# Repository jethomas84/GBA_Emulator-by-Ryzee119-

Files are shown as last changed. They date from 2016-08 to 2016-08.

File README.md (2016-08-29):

# GBA_Emulator-by-Ryzee119-

This was designed by /u/Ryzee
Originally posted on Reddit here:
https://www.reddit.com/r/DIY/comments/4zbqwr/this_is_my_attempt_at_making_a_portable_emulator/

Build Photos:
http://imgur.com/a/kjFmS

I am releasing these design files in good faith that people will use them to learn something about electronics and maybe bring an old Gameboy Advance (GBA) back to life.

I don’t want to see people taking this design and knocking it off for a quick buck.
If you don’t want to deal with all this work another redditor /u/Flav0r has designed something quite similar to this. http://gamepieadvance.com/ I understand he may be working on DIY Kits.

##DISCLAIMER:
This project is NOT for the fresh beginner or the faint of heart. It requires moderate/high level soldering skills. There are many small and fine pitch components that need to be soldered. I recommend you don’t attempt this unless you have experience in soldering, a basic ability to troubleshoot electronic circuits if things aren’t working and an ability to make mods on the fly to suit your needs. i.e cutting plastic where required.
This also requires taking apart an original GBA to repurpose the case, buttons and de-soldering of several components on the GBA motherboard. This can very tricky without the right equipment.
As a minimum the following tools are recommended (All parts should be of good quality from reputable suppliers!):

1.	A decent temperature controlled soldering station with suitable tips for fine work
2.	Solder flux
3.	Leaded solder
4.	Fine tweezers (anti-magnetic)
5.	Solder wick
6.	Multimeter for testing

This is a **FIRST PROTOTYPE** board which just happened to work reasonably ok. This has not undergone any extensive testing.

I take no responsibility for the following:

1.	You went ahead and purchased everything, soldered it up and it didn’t work.
2.	You soldered an SMD chip and bent and broke the pins.
3.	If a component in the BOM is not available or becomes obsolete, use your best judgement to find a replacement.
4.	A component was missing from the BOM. (I did check it. But it’s your responsibility to check it again against the schematic)
5.	The thing burst into flame and explodes in your hands and burns your house down.
6.	It doesn’t fit in your GBA case. (It was designed to one I had lying around. I don’t know if Nintendo did subtle changes in their cases over the years)
7.	Hours of lost productivity because you're slaying bosses and saving princesses.

Any advice and support I provide from this point is purely out of the kindness of my heart.

## ISSUES OBSERVED WITH THE BOARD:
Again, this is a first prototype. I have observed the following issues:

1. Slight buzzing from the speaker. More noticeable when volume is high and no sound is being played. I’ve added some extra decoupling caps to the area but this may or may not do a thing.

2. DC boost converter struggles at low input voltages. Although I tried to design it for this; if you use Alkaline batteries you will probably be disappointed. Once the input voltage drops below ~2.5V expect the random reboot at high loads. I recommend good quality Lithium AA batteries. Because of lithium discharge curves, the low battery indictor circuit is not particularly useful.

3. The closest screen I could find to the original is a 3.2" TFT. It is slightly bigger than the viewing window. The left and bottom edges of the screen are cut off slightly. Borders can be setup in RetroArch so the games don't have this issue, however it is visible in the game selection screens.

4. Probably more. This has not been extensively tested.

## Controls
So if you managed to get everything up and running. Congrats! If you followed the software setup guide it has the following key combos setup:

1. SELECT+START = Exit current rom
2. SELECT+A = Save current state
3. SELECT+B = Load current state
4. SELECT+RIGHT SHOULDER = High speed
5. SELECT+LEFT SHOULDER = Rewind gameplay around 3-4 seconds
6. SELECT+LEFT/RIGHT = INCREASE/DECREASE Screen brightness

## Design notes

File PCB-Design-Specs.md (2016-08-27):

## PCB Design Info

Software: Cadsoft Eagle (https://cadsoft.io/) 
Note: I have a non-commercial ‘Maker’ license. This allows a slightly larger board size than the free version. This means that if you try to edit (viewing should be ok) the PCB with the free version you may have difficulty.
I apologise for this but I wasn’t expecting to release it.

**PCB Specs:**

1.	Layers: 2
2.	PCB Thickness: 1.0mm (This is important!)
3.	Copper Weight: 1oz
4.	Surface Finish: Lead free HASL. (ENIG would be better but costs more)

The PCB fab I used for the main PCB is Elecrow (http://www.elecrow.com/). I am not affiliated with them in anyway.
If you decide to use this company, I specifically used this service:
http://www.elecrow.com/5pcs-2-layer-pcb-p-1174.html

If you make any modifications to the PCB, you can read the wiki on Elecrow’s website for help on how to regenerate the Gerbers.
The small Flat flex cable adapter can be purchased directly from:
https://oshpark.com/shared_projects/9tH3I87q
This was not possible with the main PCB as OSHPark don’t offer a 1.0mm PCB thickness.

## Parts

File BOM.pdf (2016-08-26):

Bill of Materials based on my GBA mod. By /u/Ryzee
http://imgur.com/a/kjFmS
https://www.reddit.com/r/DIY/comments/4zbqwr/this_is_my_attempt_at_making_a_portable_emulator/ Direct Digi-key shopping cart link for all Digikey parts below: http://www.digikey.com.au/short/3h8jbc

## Build at your own risk!

Qty Value | Device | Parts | Digikey part
3 100k | RES SMD 100K OHM 1% 1/8W 0805 | R5, R6, R14 | RMCF0805FT100KCT-ND (https://www.digikey.com.au/product-detail/en/stackpole-electronics-inc/RMCF0805FT100K/RMCF0805FT100KCT-ND/1942491)
6 100n | CAP CER 0.1UF 25V X7R 0805 | C1, C3, C11, C12, C16, C17 | 1276-1099-1-ND (https://www.digikey.com.au/product-detail/en/samsung-electro-mechanics-america-inc/CL21B104KACNNNC/1276-1099-1-ND/3889185)
7 10u | CAP ALUM 10UF 20% 16V SMD | C2, C5, C6, C13, C14, C15, C18 | 493-2100-1-ND (https://www.digikey.com.au/product-detail/en/nichicon/UWX1C100MCL1GB/493-2100-1-ND/590075)
1 1k | RES SMD 1K OHM 1% 1/8W 0805 | R4 | RMCF0805FT1K00CT-ND (https://www.digikey.com.au/product-detail/en/stackpole-electronics-inc/RMCF0805FT1K00/RMCF0805FT1K00CT-ND/1942370)
1 220n | CAP CER 0.22UF 16V X7R 0805 | C4 | 1276-1284-1-ND (https://www.digikey.com.au/product-detail/en/samsung-electro-mechanics-america-inc/CL21B224KOCNNNC/1276-1284-1-ND/3889370)
2 270R | RES SMD 270 OHM 1% 1/8W 0805 | R8, R15 | RMCF0805FT270RCT-ND (https://www.digikey.com.au/product-detail/en/stackpole-electronics-inc/RMCF0805FT270R/RMCF0805FT270RCT-ND/1942346)
2 27R | RES SMD 27 OHM 1% 1/8W 0805 | R2, R3 | RMCF0805FT27R0CT-ND (https://www.digikey.com.au/product-detail/en/stackpole-electronics-inc/RMCF0805FT27R0/RMCF0805FT27R0CT-ND/5049791)
1 430k | RES SMD 430K OHM 1% 1/8W 0805 | R9 | P430KCCT-ND (http://www.digikey.com.au/product-detail/en/panasonic-electronic-components/ERJ-6ENF4303V/P430KCCT-ND/1746869)
1 330n | CAP CER 0.33UF 50V X7R 0805 | C8 | 1276-1123-1-ND (https://www.digikey.com.au/product-detail/en/samsung-electro-mechanics-america-inc/CL21B334KBFNNNE/1276-1123-1-ND/3889209)
1 3R9 | RES SMD 3.9 OHM 1% 1/8W 0805 | R10 | RMCF0805FT3R90CT-ND (https://www.digikey.com.au/product-detail/en/stackpole-electronics-inc/RMCF0805FT3R90/RMCF0805FT3R90CT-ND/2418397)
1 4.7uH | FIXED IND 4.7UH 1.72A 82 MOHM | L4 | 732-1021-1-ND (https://www.digikey.com.au/product-detail/en/wurth-electronics-inc/744042004/732-1021-1-ND/1639082)
1 47k | PVZ3A473C01R00 | R11 (Use 10K version if out of stock) | 490-7795-1-ND (https://www.digikey.com.au/product-detail/en/bourns-inc/PVZ3A473C01R00/490-7795-1-ND/4358063)
3 47uF | CAP ALUM 47UF 20% 16V SMD | C9, C10 | P15090CT-ND (https://www.digikey.com.au/product-detail/en/panasonic-electronic-components/EEE-FT1C470AR/P15090CT-ND/2796927)
1 600 Ohm | FERRITE BEAD 600 OHM 0805 1LN | L1 | 240-2390-1-ND (https://www.digikey.com.au/product-detail/en/laird-signal-integrity-products/MI0805K601R-10/240-2390-1-ND/806750)
2 620R | RES SMD 620 OHM 1% 1/8W 0805 | R12, R13 | 1276-5260-1-ND (https://www.digikey.com.au/product-detail/en/samsung-electro-mechanics-america-inc/RC2012F621CS/1276-5260-1-ND/3968232)
1 976k | RES 976K OHM 1/8W 1% 0805 | R7 | 311-976KCRCT-ND (https://www.digikey.com.au/product-detail/en/yageo/RC0805FR-07976KL/311-976KCRCT-ND/731162)
1 AZV321 | IC OPAMP GEN PURP SOT25 | U7 | AZV321KTR-G1DICT-ND (https://www.digikey.com.au/product-detail/en/diodes-incorporated/AZV321KTR-G1/AZV321KTR-G1DICT-ND/4505335)
2 DFLS130L | DIODE SCHOTTKY 30V 1A POWERDI123 | D1, D2 | DFLS130LDICT-ND (https://www.digikey.com.au/product-detail/en/diodes-incorporated/DFLS130L-7/DFLS130LDICT-ND/673203)
1 XZMDKVG54W-4 LED GREEN/RED DUAL LED CLEAR 0805 SMD | D3 | 1497-1182-1-ND (https://www.digikey.com.au/product-detail/en/sunled/XZMDKVG54W-4/1497-1182-1-ND/4745895)
1 FT230X | IC USB SERIAL BASIC UART 16SSOP | U2 | 768-1154-5-ND (https://www.digikey.com.au/product-detail/en/ftdi-future-technology-devices-international-ltd/FT230XS-U/768-1154-5-ND/3749469)
1 LM4875 | IC AMP AUDIO PWR 1W MONO 8SOIC | U4 | 296-35282-1-ND (https://www.digikey.com.au/product-detail/en/texas-instruments/LM4875MX-NOPB/296-35282-1-ND/3738990)
1 MCP1642B-ADJ | IC REG BOOST ADJ 0.8A SYNC 8MSOP | U3 | MCP1642B-ADJI/MS-ND (https://www.digikey.com.au/product-detail/en/microchip-technology/MCP1642B-ADJI-MS/MCP1642B-ADJI-MS-ND/5125100)
1 MIC7211 | IC COMPARATOR R-R INPUT SOT23-5 | U6 | 576-1318-1-ND (https://www.digikey.com.au/product-detail/en/microchip-technology/MIC7211YM5-TR/576-1318-1-ND/771922)
1 IRLML6401TRPBF MOSFET P-CH 12V 4.3A SOT-23 | Q1 | IRLML6401PBFCT-ND (https://www.digikey.com.au/product-detail/en/infineon-technologies/IRLML6401TRPBF/IRLML6401PBFCT-ND/812509)
1 CLS0231MA-1-L152SPEAKER 8OHMS .5W 23MM 6" LEADS | SP1 | 102-1553-ND (https://www.digikey.com.au/product-detail/en/cui-inc/CLS0231MA-1-L152/102-1553-ND/1630867)
1 MIC5365-2.8YC5-TRIC REG LDO 2.8V 0.15A SC70-5 | U5 | 576-3187-1-ND (https://www.digikey.com.au/product-detail/en/microchip-technology/MIC5365-2.8YC5-TR/576-3187-1-ND/1868224)
1 FLAT FLEX | HF18U-02-ND CABLE FLAT FLEX 18POS 1MM 2" (https://www.digikey.com.au/product-detail/en/parlex-usa-llc/100R18-51B/HF18U-02-ND/273663) | - | HF18U-02-ND (https://www.digikey.com.au/product-detail/en/parlex-usa-llc/100R18-51B/HF18U-02-ND/273663)
1 GBA_TFT_CON | CONN FFC BOTTOM 18POS 1.00MM R/A | TFT1 | 609-1911-1-ND (https://www.digikey.com.au/product-detail/en/amphenol-fci/SFW18R-1STE1LF/609-1911-1-ND/1003200)
1 TFT DISPLAY | 3.2" 18P SPI TFT ILI9341 320x240 | - | Aliexpress (https://www.aliexpress.com/item/3-2-inch-18P-SPI-TFT-LCD-Screen-with-Touch-panel-ILI9341-Drive-IC-240-320/32556379195.html)
1 27k | Nintendo VOLUME ADJUST POT | R1 | Taken out of old GBA
1 HEADPHONE | Nintendo HEADPHONE | X2 | Taken out of old GBA
2 L+R SHOULDER | Nintendo BUTTON | SW1 | Taken out of old GBA
1 LINK_SOCKET | Nintendo LINK_SOCKET | X1 | Taken out of old GBA
1 PWR_SWITCH | Nintendo PWR_SWITCH | SW3 | Taken out of old GBA
1 RPI-ZERO | RPI-ZERO | U1 | -
2 AA Batteries | Recommendation is ENERGIZER L91 Lithium or equivalent good quality lithium AA's | | -
1 GBA Link cable | Needs to be modified with a USB male connector on one end | | eBay
1 TFT_ADAPTER_PCBADAPTER PCB FOR TFT FLAT FLEX CABLE | - | OHSPark Direct Link (https://oshpark.com/shared_projects/9tH3I87q)

NOTE: THESE ARE ALL BARE MINIMUM QUANTITIES. I RECOMMEND GETTING SPARES BECAUSE SMALL COMPONENTS CAN FLY AWAY AND THEY'RE USUALLY LOST FOREVER

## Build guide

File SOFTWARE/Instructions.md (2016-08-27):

Draft copy! Still working on this

## Software Setup
This following describes the software installation steps for my GBA mod.
The following sources were used:
https://github.com/adafruit/Adafruit-Retrogame  
https://github.com/notro/fbtft/wiki/  
https://github.com/WiringPi/WiringPi  
https://www.raspberrypi.org/forums/viewtopic.php?f=44&t=39138  

### 1. OS Installation
1.	Download RetroPie from https://retropie.org.uk/
2.	The version I used is v3.8.1
3.	Flash the .img file to an SD card using [Win32 Disk Imager](https://sourceforge.net/projects/win32diskimager/).
4.	Once the image has been flashed to the SD card a **boot** partition should appear in your PC.
5.	Place *‘gbaemu-overlay.dtbo’* into the **boot/overlays** folder.
6.	In **boot/** create a new folder called *‘gba_mod’*
7.	In the **gba_mod** folder place the following programs/files:
  1.  retrogame
  2.  gpio_alt
  3.  fbcp
  4.  es_input.cfg
  5.  retroarch.cfg
8. Go to the [WiringPi Github repo](https://github.com/WiringPi/WiringPi) and clone a zip file of the project to your desktop. Unzip all files to a folder called *'wiringpi'*
9. Copy the 'wiringpi' folder to boot/gba_mod/ on the SD card.  
10.	Edit boot/config.txt with a editor that follows the linefeeds in a linux system (i.e notepad++) and include the following at the end of the file then save and close the file:
> hdmi_force_hotplug=1  
> hdmi_group=2  
> hdmi_mode=87  
> hdmi_cvt=320 240 60 1 0 0 0  
> dtoverlay=gbaemu-overlay

11.	That’s it. Eject the SD card and put it into your modded GBA-Rasp Pi.  

### 2. First power up
1.	If you power on the GBA at this point, the TFT should turn on but you won’t be able to see anything just yet. **Turn the GBA back off**
2.	Plug your modified Gameboy link cable in the link port on the modded GBA and the USB end into your PC. If you’re running Windows, the FTDI chip should be detected and automatically installed. If not, you can install the Virtual Com Port (VCP) drivers here: http://www.ftdichip.com/Drivers/VCP.htm. The chip should still be detected even if the GBA is off as this chip is powered from the USB bus.
3.	After it has installed confirm that a COM port appears in your Device Manager
4.	Download and install [FT_PROG](http://www.ftdichip.com/Support/Utilities.htm#FT_PROG)
5.	Once installed, open the program and go DEVICES>Scan and Parse. The FTDI chip should be detected.
6.	Search through the settings and set the following options in the EEPROM:
  1.	Enable the **Bus Powered** option
  2.	Set **Max Bus Power** to 500 mA
  3.	Enable **Pull-down IO Pins in USB Suspend**
  4.	Set CBUS3 output to **PWREN#**
  5.	Go to DEVICES>Program to write the settings to the FTDI chip.  
  6.	Close FT_Prog, Remove and reinsert the GBA link cable from the USB port. Confirm that the COM port reappears in your Device Manger. Note the COM Port Number. (i.e COM3)
7.	Open up a program that allows communication of the COM Port. I have used [Putty](http://www.chiark.greenend.org.uk/~sgtatham/putty/).
8.	Select **Serial** connection type. Type in your COM Port number and Speed of 115200. Hit Open.
9.	Now power on your GBA using the power switch. You should be presented with a message *’Uncompressing Linux… done, booting the kernel.’*. Wait for the login prompt to appear. This can take about a 1 minute or more.
10.	Default login is *pi* and password is *raspberry*.
11.	After first login, a First boot script will run, and reboot the system once again.
12.	Now you can issue commands to the Raspberry Pi Zero over the command line!

### 3. Configuration of System.
1.	Issue the following commands one at a time:
> sudo cp /boot/gba_mod/retrogame /usr/local/bin/retrogame  
> sudo cp /boot/gba_mod/gpio_alt /usr/local/bin/gpio_alt  
> sudo cp /boot/gba_mod/fbcp /usr/local/bin/fbcp  
> sudo cp /boot/gba_mod/retroarch.cfg /opt/retropie/configs/all/retroarch.cfg  
> sudo cp /boot/gba_mod/es_input.cfg /opt/retropie/configs/all/emulationstation/es_input.cfg  
> cd /boot/gba_mod/wiringpi  
> sudo ./build  

2. Enter the Rasp Pi config screen
>sudo raspi-config

3. Set the following options:  
  1. Disable overscan  
  2. Force 3.5mm audio (headphone)  
  3. Enable SPI  
  4. Exit raspi-config. There's no need to reboot just yet.

4.	To set the programs to begin at startup edit /etc/rc.local
> sudo nano /etc/rc.local

5. Add the following to the end of the file but **before** exit 0.
> fbcp &  
> retrogame &  
> gpio_alt -p 18 -f 5

6.	Setup virtual keyboard by the following:
> sudo nano /etc/udev/rules.d/10-retrogame.rules

   and add the following to this file:
> SUBSYSTEM=="input", ATTRS{name}=="retrogame", ENV{ID_INPUT_KEYBOARD}="1"

   Increase the font size in EmulationStation for readability by the following:
> sudo nano /etc/emulationstation/themes/carbon/carbon.xml

   Then scroll down to the ‘gamelist’ section and change any occurance of fontSize to 0.05.

7.	Reboot and you should have everything up and running!
8.	(Optional) In EmulationStation goto the ‘RetroPie’ menu item and explore all the options available to tweak how you like it.

### 4. Get ROMS onto it
1.	The easiest way to do this is to get a microUSB to USB adapter and connect a wifi dongle to the Raspberry Pi USB port. To setup wifi, do the following in the serial console:
> sudo nano /etc/wpa_supplicant/wpa_supplicant.conf

   Add the following and replace with your wifi info:
>network={  
>	ssid=”YOURWIFINAME”  
> 	psk=”YOURPASSWORD”  
>}  

2.	Reboot device and confirm that it connects to the wifi network. Check your IP by issuing the following into the serial console:
> ifconfig

3.	Located your IP under wlan0 and note this number.
4.	Download [WinSCP](https://winscp.net/eng/download.php). Setup a SFTP session using your IP address, Port 22 and username *pi* and password *raspberry*.
5.	Copy ROMS to their respective folders in **/home/pi/RetroPie/roms/**
6. Alternatively, if you're able to read the linux partition on your PC, your could remove the SD card and place it in your computer and copy them over directly.

### 5. Make console better (Optional)
1. This step makes the text on the console a bit easier to read on the small screen. In the serial console perform the following:
> sudo dpkg-reconfigure console-setup

   Select “UTF-8”, “Guess optimal character set”, “Terminus” and “6x12 (framebuffer only).”

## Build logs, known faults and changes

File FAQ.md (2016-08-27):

## FAQ and anticipated FAQ

**Q: How’d you learn all this:**

A: I’m an Electrical Engineer and its my career, but I do PCB design as a hobby only. I don’t do board level design at work!
If you want to get into electronics this is NOT the only pathway, but it’s difficult for me to provide advice for your personal case. Mine is a long hard road and certainly not the best/most efficient way for you.

**Q: Are you making DIY Kits that I can just buy?**

A: I have no plans to do this. The info I have provided should be enough to get everything you need. Another redditor /u/Flav0r has designed something quite similar to this. See http://gamepieadvance.com/ I understand he may be working on DIY Kits.

**Q: I can view the PCB but can’t edit it?**

A: Great to see you having a play with it. However, I must apologise as I did not expect to share this and it exceeds the size limitations for the Free version of eagle. I have a non-commercial ‘Maker’ license. If you’re a student I think you can get this for free.

**Q: What software does the Raspberry Pi Run?**

A: https://retropie.org.uk/ - A system specifically designed for emulators.

**Q: How long does is take to boot up?**

A: I measured this at around 1 minute 15 seconds.

**Q: Can you build me one? Name a price!**

A: Sorry, I’d love to help people out, but I don’t want to turn my hobby into an income stream. I do this for fun and don’t want to ruin it for myself.

**Q: What’s the battery life like?**

A: A very nominal power consumption is 330mA. The batteries I recommend are good quality Lithium AAs. These should give approximately 3000mAH before you have issues. This is a theoretical time of around 9 hours but don’t expect this. 5-6 hours is a more ‘real-life’ number.

**Q: How does the TFT screen perform over SPI?**

A: I am using Notro’s FBTFT framebuffer driver. https://github.com/notro/fbtft/wiki/Framebuffer-use. Quote: *“Snapshotting takes ~10ms and with a 25ms delay it gives roughly 1000/(10+25) = 28fps CPU usage: ~2%”*

**Q: Why didn’t you…. <insert feature here>?**

A: I got lots of great ideas and additions from people. I designed it for myself and the time/money I was willing to spend on it.

**Q: What’s the cost?**

A: Get a quote for the PCB and add up the BOM cost. Your shipping rates may vary a lot from mine (To Australia).

**Q: I have this issue can you help me?**

A: Any support I provide is out of the kindness of my heart. I may or may not respond depending if I see it/have time.

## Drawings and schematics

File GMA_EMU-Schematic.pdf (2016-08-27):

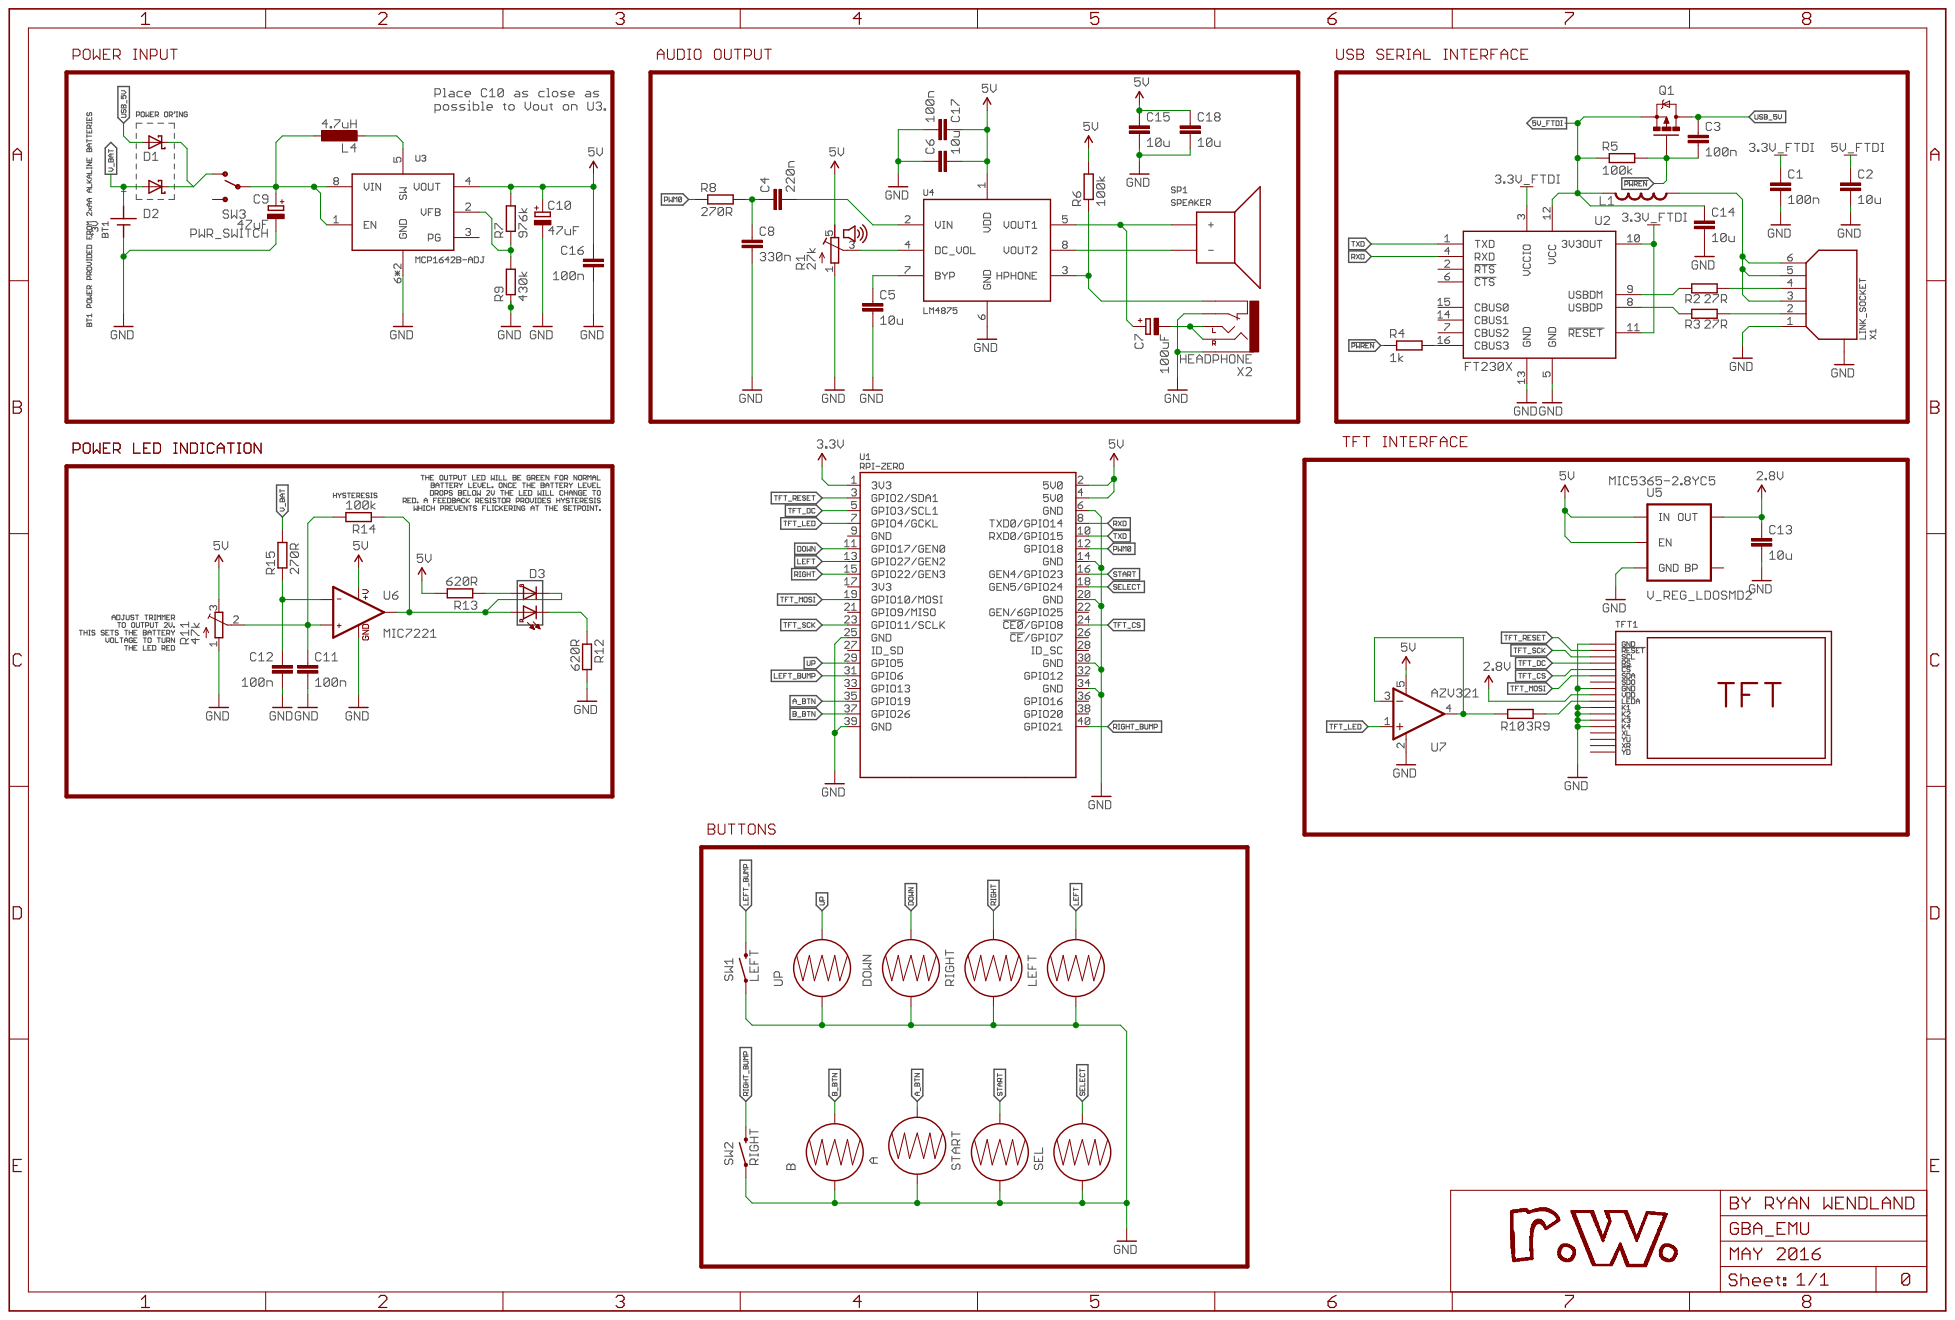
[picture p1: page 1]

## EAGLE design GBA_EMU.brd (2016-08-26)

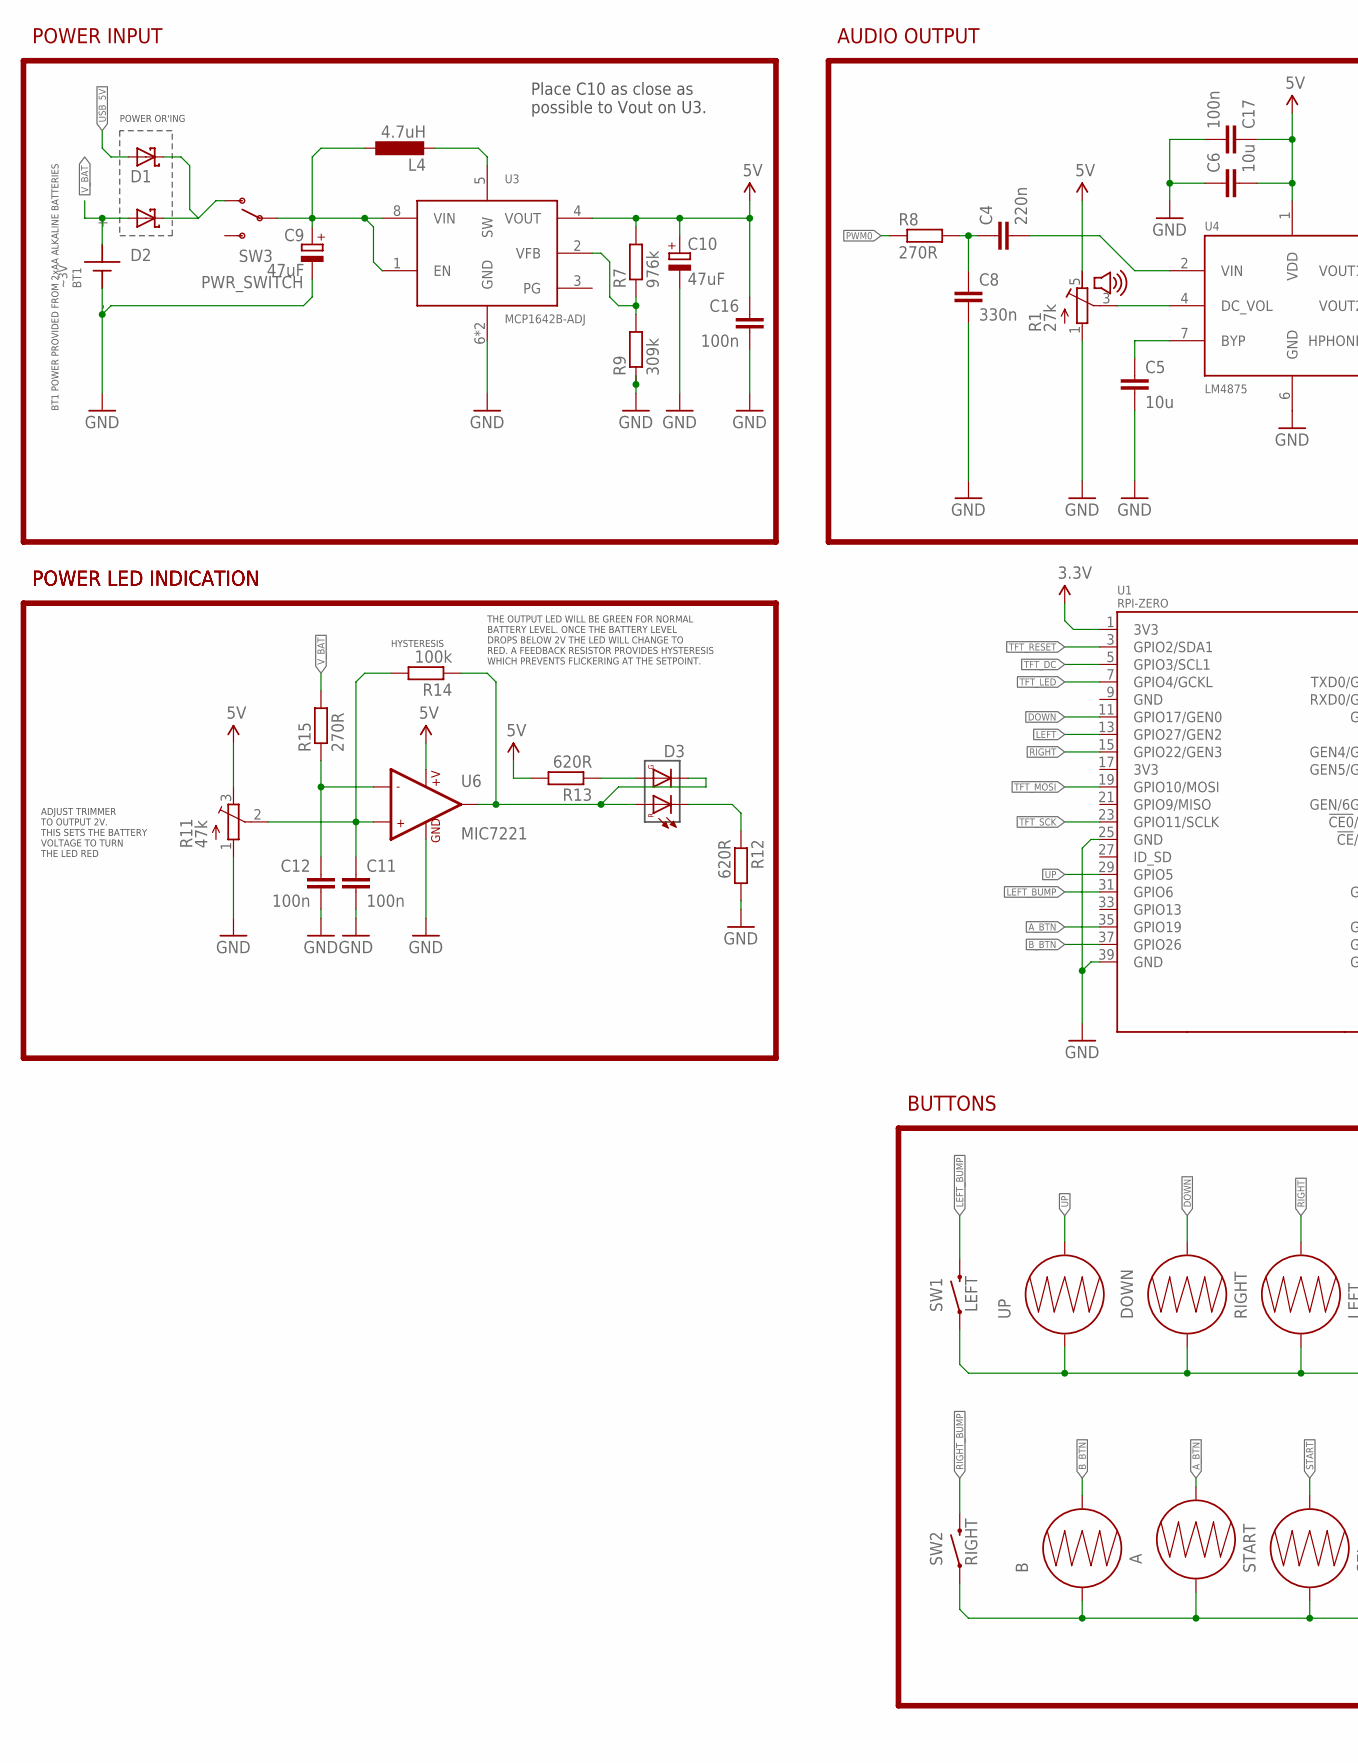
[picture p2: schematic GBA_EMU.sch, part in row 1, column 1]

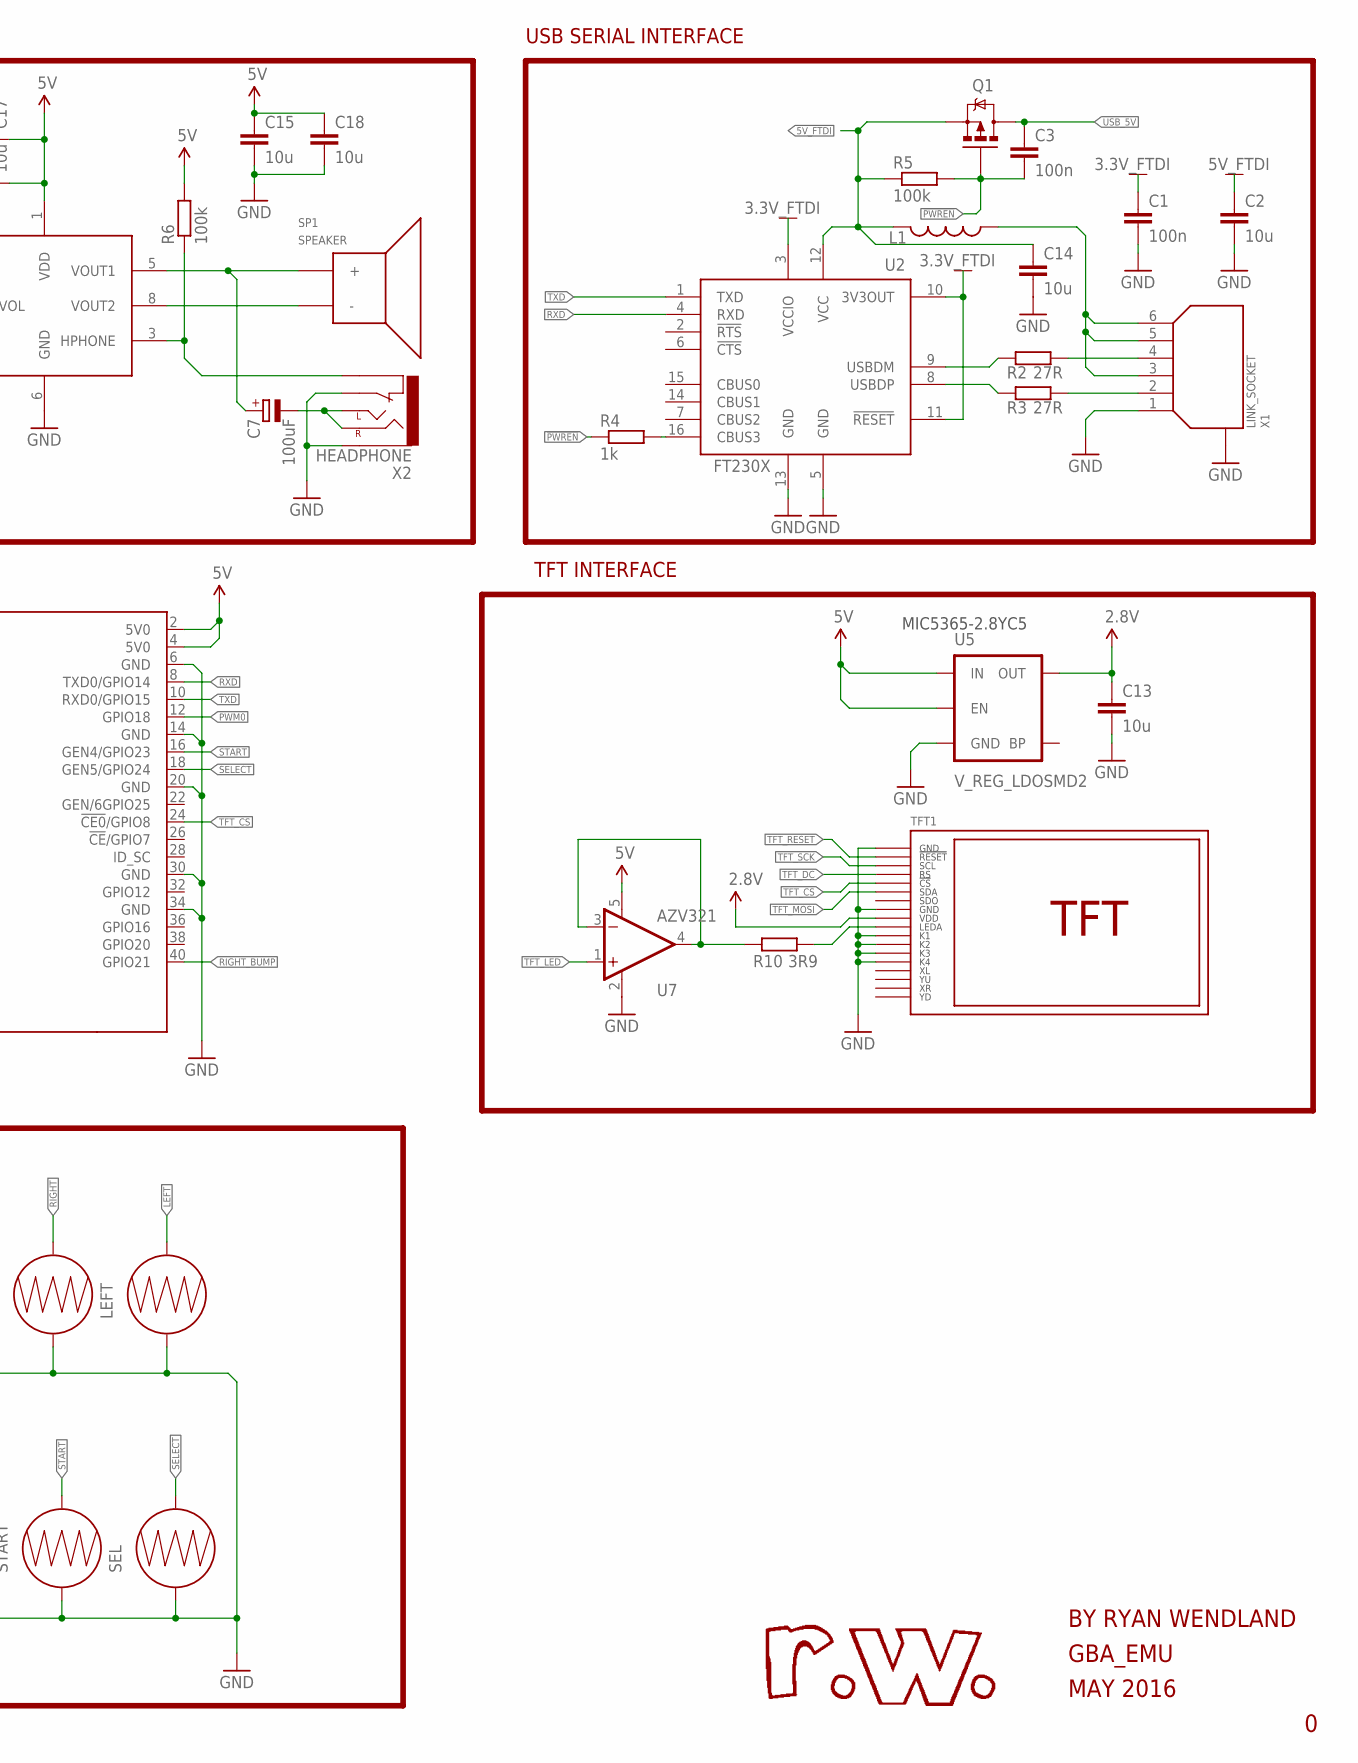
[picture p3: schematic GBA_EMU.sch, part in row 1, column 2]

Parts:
A: GBA_BTN_CONDUCTIVE; GBA_BUTTON_CONDUCTIVE
B: GBA_BTN_CONDUCTIVE; GBA_BUTTON_CONDUCTIVE
BT1: ~3V; BATTERY
C1, C3, C11, C12, C16, C17: 100n; C0805
C2, C5, C6, C13, C14, C15, C18: 10u; C0805
C4: 220n; C0805
C7: 100uF; 153CLV-0405
C8: 330n; C0805
C9, C10: 47uF; 153CLV-0405
D1, D2: DFLS130L; POWERDI_123
D3: DUAL_LED
DOWN: GBA_BTN_CONDUCTIVE; GBA_BUTTON_CONDUCTIVE
L1: 600; 0805
L4: 4.7uH; POWER-CHOKE_WE-TPC
LEFT: GBA_BTN_CONDUCTIVE; GBA_BUTTON_CONDUCTIVE
Q1: MOSFET-PCHANNEL; SOT23-3
R1: 27k; VOLUME
R2, R3: 27R; R0805
R4: 1k; R0805
R5, R6, R14: 100k; R0805
R7: 976k; R0805
R8, R15: 270R; R0805
R9: 309k; R0805
R10: 3R9; R0805
R11: 47k; TC33X
R12, R13: 620R; R0805
RIGHT: GBA_BTN_CONDUCTIVE; GBA_BUTTON_CONDUCTIVE
SEL: BUTTON-CONDUCTIVESMD; BUTTON-CONDUCTIVE
SP1: SPEAKER
START: BUTTON-CONDUCTIVESMD; BUTTON-CONDUCTIVE
SW1: LEFT; BUMPER
SW2: RIGHT; BUMPER
SW3: PWR_SWITCH
TFT1: GBA_TFT
U1: RPI-ZERO; RASPBERRYPI_BASTELSTUBE_V13_RASPI_BOARD_B+_FULL
U2: FT230X; SSOP16
U3: MCP1642B-ADJ; MSOP8
U4: LM4875; SOIC8
U5: V_REG_LDOSMD2; SC70
U6: MIC7221; SOT23-5
U7: AZV321; SOT23-5
UP: GBA_BTN_CONDUCTIVE; GBA_BUTTON_CONDUCTIVE
X1: LINK_SOCKET
X2: HEADPHONE

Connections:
0.8128: C9.+, L4.1, SW3.COM1, SW3.COM2, U3.1 (EN), U3.8 (VIN)
2.8V: C13.1, TFT1.9 (VDD), U5.5 (OUT)
3.3V: U1.1 (3V3)
3.3V_FTDI: C1.1, U2.3 (VCCIO), U2.10 (3V3OUT), U2.11 (!RESET)
5V: C6.2, C10.+, C15.1, C16.1, C17.1, C18.1, R1.5 (E), R6.2, R7.2, R11.3 (E), R13.2, U1.2 (5V0), U1.4 (5V0), U3.4 (VOUT), U4.1 (VDD), U5.1 (IN), U5.3 (EN), U6.2 (+V), U7.5 (V+)
5V_FTDI: C2.1, C14.1, L1.1, Q1.2 (S), R5.1, U2.12 (VCC)
!PWREN: C3.2, Q1.1 (G), R4.1, R5.2
A_BTN: A.2, U1.35 (GPIO19)
B_BTN: B.2, U1.37 (GPIO26)
DOWN: DOWN.2, U1.11 (GPIO17/GEN0)
GND: A.1, B.1, BT1.BT-1 (-), BT1.BT-2 (-), C1.2, C2.2, C5.2, C6.1, C8.2, C9.-, C10.-, C11.2, C12.2, C13.2, C14.2, C15.2, C16.2, C17.2, C18.2, DOWN.1, LEFT.1, R1.1 (A), R9.1, R11.1 (A), R12.2, RIGHT.1, SEL.1, START.1, SW1.1, SW2.1, TFT1.1 (GND), TFT1.8 (GND), TFT1.11 (K1), TFT1.12 (K2), TFT1.13 (K3), TFT1.14 (K4), U1.6 (GND), U1.14 (GND), U1.20 (GND), U1.25 (GND), U1.30 (GND), U1.34 (GND), U1.39 (GND), U2.5 (GND), U2.13 (GND), U3.6 (GND), U3.7 (GND), U4.6 (GND), U5.2 (GND), U6.5 (GND), U7.2 (V-), UP.1, X1.1, X1.GND@1 (GND), X1.GND@2 (GND), X2.1, X2.GND
LEFT: LEFT.2, U1.13 (GPIO27/GEN2)
LEFT_BUMP: SW1.2, U1.31 (GPIO6)
unnamed: C11.1, R11.2 (S), R14.2, U6.3 (+IN1)
unnamed: C4.1, C8.1, R8.2
unnamed: L1.2, X1.3, X1.5, X1.6
unnamed: R2.2, X1.4
unnamed: R3.2, X1.2
unnamed: R2.1, U2.9 (USBDM)
unnamed: R3.1, U2.8 (USBDP)
unnamed: R1.3 (S), U4.4 (DC_VOL)
unnamed: C4.2, U4.2 (VIN)
unnamed: R4.2, U2.16 (CBUS3)
unnamed: C5.1, U4.7 (BYP)
unnamed: L4.2, U3.5 (SW)
unnamed: C7.-, X2.L (LEFT), X2.R (RIGHT)
unnamed: C7.+, SP1.1 (+), U4.5 (VOUT1)
unnamed: SP1.2 (-), U4.8 (VOUT2)
unnamed: R6.1, U4.3 (HPHONE), X2.2
unnamed: D1.2 (C), D2.2 (C), SW3.1 (O)
unnamed: D3.1, D3.3, R14.1, U6.1 (OUT1)
unnamed: R7.1, R9.2, U3.2 (VFB)
unnamed: R10.2, TFT1.10 (LEDA)
unnamed: D3.4, R13.1
unnamed: D3.2, R12.1
unnamed: R10.1, U7.3 (-IN), U7.4 (OUT)
unnamed: C12.1, R15.1, U6.4 (-IN1)
PWM0: R8.1, U1.12 (GPIO18)
RIGHT: RIGHT.2, U1.15 (GPIO22/GEN3)
RIGHT_BUMP: SW2.2, U1.40 (GPIO21)
RXD: U1.8 (TXD0/GPIO14), U2.4 (RXD)
SELECT: SEL.2, U1.18 (GEN5/GPIO24)
START: START.2, U1.16 (GEN4/GPIO23)
TFT_CS: TFT1.5 (!CS), U1.24 (!CE0!/GPIO8)
TFT_DC: TFT1.4 (RS), U1.5 (GPIO3/SCL1)
TFT_LED: U1.7 (GPIO4/GCKL), U7.1 (+IN)
TFT_MOSI: TFT1.6 (SDA), U1.19 (GPIO10/MOSI)
TFT_RESET: TFT1.2 (!RESET), U1.3 (GPIO2/SDA1)
TFT_SCK: TFT1.3 (SCL), U1.23 (GPIO11/SCLK)
TXD: U1.10 (RXD0/GPIO15), U2.1 (TXD)
UP: U1.29 (GPIO5), UP.2
USB_5V: C3.1, D1.1 (A), Q1.3 (D)
V_BAT: BT1.BT+1 (+), BT1.BT+2 (+), D2.1 (A), R15.2

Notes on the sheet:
USB SERIAL INTERFACE
AUDIO OUTPUT
POWER INPUT
POWER OR'ING
BT1 POWER PROVIDED FROM 2xAA ALKALINE BATTERIES
TFT INTERFACE
ADJUST TRIMMER TO OUTPUT 2V. THIS SETS THE BATTERY VOLTAGE TO TURN THE LED RED
HYSTERESIS
POWER LED INDICATION
THE OUTPUT LED WILL BE GREEN FOR NORMAL BATTERY LEVEL. ONCE THE BATTERY LEVEL DROPS BELOW 2V THE LED WILL CHANGE TO RED. A FEEDBACK RESISTOR PROVIDES HYSTERESIS WHICH PREVENTS FLICKERING AT THE SETPOINT.
GBA_EMU
MAY 2016
BY RYAN WENDLAND
BUTTONS
Place C10 as close as possible to Vout on U3.
MIC5365-2.8YC5

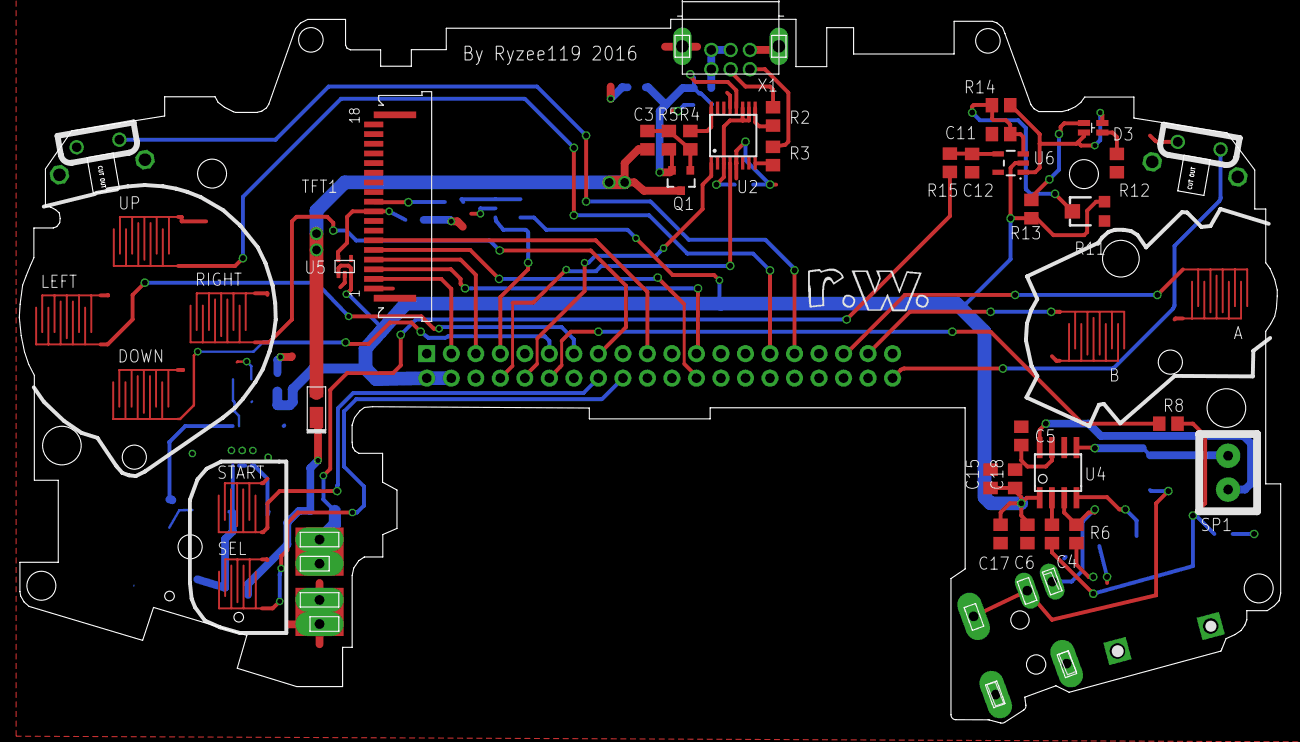
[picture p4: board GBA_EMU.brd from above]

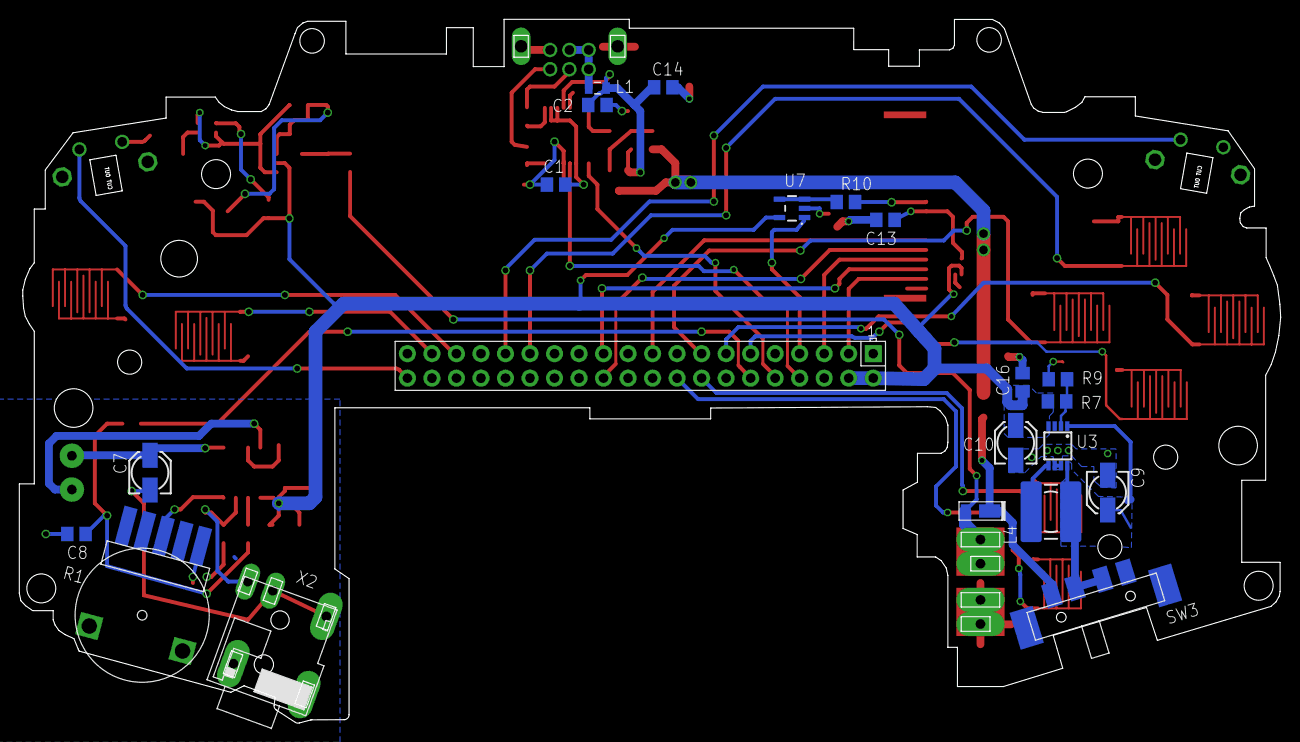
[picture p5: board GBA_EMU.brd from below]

Board: 2 copper layers, 130.7 x 72.9 mm, 62 parts (21 on the bottom side), 52 nets.

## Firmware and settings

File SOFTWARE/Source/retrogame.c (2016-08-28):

/*
This Program has been modified by Ryzee119 for use with a GBA mod design by me.
https://github.com/Ryzee119/GBA_Emulator-by-Ryzee119-
http://imgur.com/a/kjFmS

All credits to ADAFRUIT for developing this.
Originally pulled from https://github.com/adafruit/Adafruit-Retrogame

ADAFRUIT RETROGAME UTILITY: remaps buttons on Raspberry Pi GPIO header
to virtual USB keyboard presses.  Great for classic game emulators!
Retrogame is interrupt-driven and efficient (usually under 0.3% CPU use)
and debounces inputs for glitch-free gaming.

Connect one side of button(s) to GND pin (there are several on the GPIO
header, but see later notes) and the other side to GPIO pin of interest.
Internal pullups are used; no resistors required.  Avoid pins 8 and 10;
these are configured as a serial port by default on most systems (this
can be disabled but takes some doing).  Pin configuration is currently
set in global table; no config file yet.  See later comments.

Must be run as root, i.e. 'sudo ./retrogame &' or configure init scripts
to launch automatically at system startup.

Requires uinput kernel module.  This is typically present on popular
Raspberry Pi Linux distributions but not enabled on some older varieties.
To enable, either type:

    sudo modprobe uinput

Or, to make this persistent between reboots, add a line to /etc/modules:

    uinput

Prior versions of this code, when being compiled for use with the Cupcade
or PiGRRL projects, required CUPCADE to be #defined.  This is no longer
the case; instead a test is performed to see if a PiTFT is connected, and
one of two I/O tables is automatically selected.

Written by Phil Burgess for Adafruit Industries, distributed under BSD
License.  Adafruit invests time and resources providing this open source
code, please support Adafruit and open-source hardware by purchasing
products from Adafruit!


Copyright (c) 2013 Adafruit Industries.
All rights reserved.

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
- Redistributions of source code must retain the above copyright notice,
  this list of conditions and the following disclaimer.
- Redistributions in binary form must reproduce the above copyright notice,
  this list of conditions and the following disclaimer in the documentation
  and/or other materials provided with the distribution.

THIS SOFTWARE IS PROVIDED BY THE COPYRIGHT HOLDERS AND CONTRIBUTORS "AS IS"
AND ANY EXPRESS OR IMPLIED WARRANTIES, INCLUDING, BUT NOT LIMITED TO, THE
IMPLIED WARRANTIES OF MERCHANTABILITY AND FITNESS FOR A PARTICULAR PURPOSE
ARE DISCLAIMED. IN NO EVENT SHALL THE COPYRIGHT HOLDER OR CONTRIBUTORS BE
LIABLE FOR ANY DIRECT, INDIRECT, INCIDENTAL, SPECIAL, EXEMPLARY, OR
CONSEQUENTIAL DAMAGES (INCLUDING, BUT NOT LIMITED TO, PROCUREMENT OF
SUBSTITUTE GOODS OR SERVICES; LOSS OF USE, DATA, OR PROFITS; OR BUSINESS
INTERRUPTION) HOWEVER CAUSED AND ON ANY THEORY OF LIABILITY, WHETHER IN
CONTRACT, STRICT LIABILITY, OR TORT (INCLUDING NEGLIGENCE OR OTHERWISE)
ARISING IN ANY WAY OUT OF THE USE OF THIS SOFTWARE, EVEN IF ADVISED OF THE
POSSIBILITY OF SUCH DAMAGE.
*/

#include <stdio.h>
#include <stdlib.h>
#include <string.h>
#include <unistd.h>
#include <fcntl.h>
#include <poll.h>
#include <signal.h>
#include <dirent.h>
#include <sys/mman.h>
#include <sys/stat.h>
#include <sys/signalfd.h>
#include <linux/input.h>
#include <linux/uinput.h>
#include <wiringPi.h>
#include <softPwm.h>


// START HERE ------------------------------------------------------------
// This table remaps GPIO inputs to keyboard values.  In this initial
// implementation there's a 1:1 relationship (can't attach multiple keys
// to a button) and the list is fixed in code; there is no configuration
// file.  Buttons physically connect between GPIO pins and ground.  There
// are only a few GND pins on the GPIO header, so a breakout board is
// often needed.  If you require just a couple extra ground connections
// and have unused GPIO pins, set the corresponding key value to GND to
// create a spare ground point.

#define GND -1
struct {
	int pin;
	int key;
} *io, // In main() this pointer is set to one of the two tables below.
   ioGBA[] = {
	// Input	Output (from /usr/include/linux/input.h)
	{   27,     KEY_LEFT     	}, 
	{   22,     KEY_RIGHT    	},
	{   17,     KEY_DOWN     	},
	{    5,     KEY_UP       	},
	{   19,     KEY_Z        	},  // A
	{   26,     KEY_X        	},  // B
	{   24,     KEY_RIGHTSHIFT 	},  // Select
	{   23,     KEY_ENTER    	},  // Start
	{    6,	    KEY_O			},  // Left Bumper
	{   21,	    KEY_P	 		},  // Right Bumper
	{   -1,     -1          	}}; // END OF LIST, DO NOT CHANGE
	// MAME must be configured with 'z' & 'x' as buttons 1 & 2 -
	// this was required for the accompanying 'menu' utility to
	// work (catching crtl/alt w/ncurses gets totally NASTY).


// A "Vulcan nerve pinch" (holding down a specific button combination
// for a few seconds) issues an 'esc' keypress to MAME (which brings up
// an exit menu or quits the current game).  The button combo is
// configured with a bitmask corresponding to elements in the above io[]
// array.  The default value here uses elements 6 and 7 (credit and start
// in the Cupcade pinout).  If you change this, make certain it's a combo
// that's not likely to occur during actual gameplay (i.e. avoid using
// joystick directions or hold-for-rapid-fire buttons).
// Also key auto-repeat times are set here.  This is for navigating the
// game menu using the 'gamera' utility; MAME disregards key repeat
// events (as it should).
const unsigned long vulcanMaskA = (1L << 6) | (1L << 0), //Select + Left
					vulcanMaskB = (1L << 6) | (1L << 1); //Select + Right
const int           vulcanKey  = KEY_ESC, // Keycode to send
                    vulcanTimeA = 21,    // Pinch time in milliseconds
					vulcanTimeB = 22,    // Pinch time in milliseconds
                    repTime1   = 200,     // Key hold time to begin repeat
                    repTime2   = 100;     // Time between key repetitions


// A few globals ---------------------------------------------------------

extern char
  *__progname,                       // Program name (for error reporting)
  *program_invocation_name;          // Full name as invoked (path, etc.)
char
   sysfs_root[] = "/sys/class/gpio", // Location of Sysfs GPIO files
   running      = 1;                 // Signal handler will set to 0 (exit)
volatile unsigned int
  *gpio;                             // GPIO register table
const int
   debounceTime = 20;                // 20 ms for button debouncing
int brightness = 50;				 // Brightness% of TFT. Initial value is 80%
const int bright_interval = 10;		 // Amount brightness changes each press.

// Some utility functions ------------------------------------------------

// Set one GPIO pin attribute through the Sysfs interface.
int pinConfig(int pin, char *attr, char *value) {
	char filename[50];
	int  fd, w, len = strlen(value);
	sprintf(filename, "%s/gpio%d/%s", sysfs_root, pin, attr);
	if((fd = open(filename, O_WRONLY)) < 0) return -1;
	w = write(fd, value, len);
	close(fd);
	return (w != len); // 0 = success
}

// Un-export any Sysfs pins used; don't leave filesystem cruft.  Also
// restores any GND pins to inputs.  Write errors are ignored as pins
// may be in a partially-initialized state.
void cleanup() {
	char buf[50];
	int  fd, i;
	sprintf(buf, "%s/unexport", sysfs_root);
	if((fd = open(buf, O_WRONLY)) >= 0) {
		for(i=0; io[i].pin >= 0; i++) {
			// Restore GND items to inputs
			if(io[i].key == GND)
				pinConfig(io[i].pin, "direction", "in");
			// And un-export all items regardless
			sprintf(buf, "%d", io[i].pin);
			write(fd, buf, strlen(buf));
		}
		close(fd);
	}
}

// Quick-n-dirty error reporter; print message, clean up and exit.
void err(char *msg) {
	printf("%s: %s.  Try 'sudo %s'.\n", __progname, msg,
	  program_invocation_name);
	cleanup();
	exit(1);
}

// Detect Pi board type.  Doesn't return super-granular details,
// just the most basic distinction needed for GPIO compatibility:
// 0: Pi 1 Model B revision 1
// 1: Pi 1 Model B revision 2, Model A, Model B+, Model A+
// 2: Pi 2 Model B

static int boardType(void) {
	FILE *fp;
	char  buf[1024], *ptr;
	int   n, board = 1; // Assume Pi1 Rev2 by default

	// Relies on info in /proc/cmdline.  If this becomes unreliable
	// in the future, alt code below uses /proc/cpuinfo if any better.
#if 1
	if((fp = fopen("/proc/cmdline", "r"))) {
		while(fgets(buf, sizeof(buf), fp)) {
			if((ptr = strstr(buf, "mem_size=")) &&
			   (sscanf(&ptr[9], "%x", &n) == 1) &&
			   (n == 0x3F000000)) {
				board = 2; // Appears to be a Pi 2
				break;
			} else if((ptr = strstr(buf, "boardrev=")) &&
			          (sscanf(&ptr[9], "%x", &n) == 1) &&
			          ((n == 0x02) || (n == 0x03))) {
				board = 0; // Appears to be an early Pi
				break;
			}
		}
		fclose(fp);
	}
#else
	char s[8];
	if((fp = fopen("/proc/cpuinfo", "r"))) {
		while(fgets(buf, sizeof(buf), fp)) {
			if((ptr = strstr(buf, "Hardware")) &&
			   (sscanf(&ptr[8], " : %7s", s) == 1) &&
			   (!strcmp(s, "BCM2709"))) {
				board = 2; // Appears to be a Pi 2
				break;
			} else if((ptr = strstr(buf, "Revision")) &&
			          (sscanf(&ptr[8], " : %x", &n) == 1) &&
			          ((n == 0x02) || (n == 0x03))) {
				board = 0; // Appears to be an early Pi
				break;
			}
		}
		fclose(fp);
	}
#endif

	return board;
}

// Filter function for scandir(), identifies possible device candidates
// for simulated keypress events (separate from actual USB keyboard(s)).
static int filter1(const struct dirent *d) {
	if(!strncmp(d->d_name, "input", 5)) { // Name usu. 'input' + #
		// Read contents of 'name' file inside this subdirectory,
		// if it matches the retrogame executable, that's probably
		// the device we want...
		char  filename[100], line[100];
		FILE *fp;
		sprintf(filename, "/sys/devices/virtual/input/%s/name",
		  d->d_name);
		memset(line, 0, sizeof(line));
		if((fp = fopen(filename, "r"))) {
			fgets(line, sizeof(line), fp);
			fclose(fp);
		}
		if(!strncmp(line, __progname, strlen(__progname))) return 1;
	}

        return 0;
}

// A second scandir() filter, checks for filename of 'event' + #
static int filter2(const struct dirent *d) {
	return !strncmp(d->d_name, "event", 5);
}

// Main stuff ------------------------------------------------------------

#define PI1_BCM2708_PERI_BASE 0x20000000
#define PI1_GPIO_BASE         (PI1_BCM2708_PERI_BASE + 0x200000)
#define PI2_BCM2708_PERI_BASE 0x3F000000
#define PI2_GPIO_BASE         (PI2_BCM2708_PERI_BASE + 0x200000)
#define BLOCK_SIZE            (4*1024)
#define GPPUD                 (0x94 / 4)
#define GPPUDCLK0             (0x98 / 4)

int main(int argc, char *argv[]) {

	// A few arrays here are declared with 32 elements, even though
	// values aren't needed for io[] members where the 'key' value is
	// GND.  This simplifies the code a bit -- no need for mallocs and
	// tests to create these arrays -- but may waste a handful of
	// bytes for any declared GNDs.
	char                   buf[50],      // For sundry filenames
	                       c,            // Pin input value ('0'/'1')
	                       board;        // 0=Pi1Rev1, 1=Pi1Rev2, 2=Pi2
	int                    fd, fd2,      // For mmap, sysfs, uinput
	                       i, j, j3,     // Asst. counter
	                       bitmask,      // Pullup enable bitmask
	                       timeout = -1, // poll() timeout
	                       intstate[32], // Last-read state
	                       extstate[32], // Debounced state
	                       lastKey = -1; // Last key down (for repeat)
	unsigned long          bitMask, bit; // For Vulcan pinch detect
	volatile unsigned char shortWait;    // Delay counter
	struct input_event     keyEv, synEv; // uinput events
	struct pollfd          p[35];        // File descriptors for poll()
	sigset_t               sigset;       // Signal mask
	wiringPiSetup();
	softPwmCreate(7,brightness,100);
	//printf("PWM created for pin 7\n");
	// Catch all signal types so GPIO cleanup on exit is possible
	sigfillset(&sigset);
	sigprocmask(SIG_BLOCK, &sigset, NULL);
	// pollfd #0 is for catching signals...
	p[0].fd      = signalfd(-1, &sigset, 0);
	p[0].events  = POLLIN | POLLERR | POLLHUP;
	p[0].revents = 0;

	// pollfd #1 and #2 will be used for detecting changes in the
	// config file and its parent directory.  Config files ARE NOT
	// YET IMPLEMENTED, but I'm working toward this incrementally.
	// This change detection will let you edit the config and have
	// immediate feedback without needing to kill the process or
	// reboot the system.
	p[1].fd     = -1;
	p[1].events =  0;
	p[2].fd     = -1;
	p[2].events =  0;

	// p[0-2] NEVER CHANGE for the remainder of the application's
	// lifetime.  p[3...n] are then related to GPIO states, and will
	// be reconfigured each time the config file is loaded (to-do).

	// Select io[] table.
	io = ioGBA;

	// If this is a "Revision 1" Pi board (no mounting holes),
	// remap certain pin numbers in the io[] array for compatibility.
	// This way the code doesn't need modification for old boards.
	board = boardType();
	if(board == 0) {
		for(i=0; io[i].pin >= 0; i++) {
			if(     io[i].pin ==  2) io[i].pin = 0;
			else if(io[i].pin ==  3) io[i].pin = 1;
			else if(io[i].pin == 27) io[i].pin = 21;
		}
	}

	// ----------------------------------------------------------------
	// Although Sysfs provides solid GPIO interrupt handling, there's
	// no interface to the internal pull-up resistors (this is by
	// design, being a hardware-dependent feature).  It's necessary to
	// grapple with the GPIO configuration registers directly to enable
	// the pull-ups.  Based on GPIO example code by Dom and Gert van
	// Loo on elinux.org

	if((fd = open("/dev/mem", O_RDWR | O_SYNC)) < 0)
		err("Can't open /dev/mem");
	gpio = mmap(            // Memory-mapped I/O
	  NULL,                 // Any adddress will do
	  BLOCK_SIZE,           // Mapped block length
	  PROT_READ|PROT_WRITE, // Enable read+write
	  MAP_SHARED,           // Shared with other processes
	  fd,                   // File to map
	  (board == 2) ?
	   PI2_GPIO_BASE :      // -> GPIO registers
	   PI1_GPIO_BASE);

	close(fd);              // Not needed after mmap()
	if(gpio == MAP_FAILED) err("Can't mmap()");
	// Make combined bitmap of pullup-enabled pins:
	for(bitmask=i=0; io[i].pin >= 0; i++)
		if(io[i].key != GND) bitmask |= (1 << io[i].pin);
	gpio[GPPUD]     = 2;                    // Enable pullup
	for(shortWait=150;--shortWait;);        // Min 150 cycle wait
	gpio[GPPUDCLK0] = bitmask;              // Set pullup mask
	for(shortWait=150;--shortWait;);        // Wait again
	gpio[GPPUD]     = 0;                    // Reset pullup registers
	gpio[GPPUDCLK0] = 0;
	(void)munmap((void *)gpio, BLOCK_SIZE); // Done with GPIO mmap()

	// ----------------------------------------------------------------
	// All other GPIO config is handled through the sysfs interface.

	sprintf(buf, "%s/export", sysfs_root);
	if((fd = open(buf, O_WRONLY)) < 0) // Open Sysfs export file
		err("Can't open GPIO export file");
	for(i=0,j=3; io[i].pin >= 0; i++) { // For each pin of interest...
		sprintf(buf, "%d", io[i].pin);
		write(fd, buf, strlen(buf));             // Export pin
		pinConfig(io[i].pin, "active_low", "0"); // Don't invert
		if(io[i].key == GND) {
			// Set pin to output, value 0 (ground)
			if(pinConfig(io[i].pin, "direction", "out") ||
			   pinConfig(io[i].pin, "value"    , "0"))
				err("Pin config failed (GND)");
		} else {
			// Set pin to input, detect rise+fall events
			if(pinConfig(io[i].pin, "direction", "in") ||
			   pinConfig(io[i].pin, "edge"     , "both"))
				err("Pin config failed");
			// Get initial pin value
			sprintf(buf, "%s/gpio%d/value",
			  sysfs_root, io[i].pin);
			// The p[] file descriptor array isn't necessarily
			// aligned with the io[] array.  GND keys in the
			// latter are skipped, but p[] requires contiguous
			// entries for poll().  So the pins to monitor are
			// at the head of p[], and there may be unused
			// elements at the end for each GND.  Same applies
			// to the intstate[] and extstate[] arrays.
			if((p[j].fd = open(buf, O_RDONLY)) < 0)
				err("Can't access pin value");
			j3 = j - 3; // Signal fds occupy first 3 slots
			intstate[j3] = 0;
			if((read(p[j].fd, &c, 1) == 1) && (c == '0'))
				intstate[j3] = 1;
			extstate[j3] = intstate[j3];
			p[j].events  = POLLPRI; // Set up poll() events
			p[j].revents = 0;
			j++;
		}
	} // 'j' is now count of non-GND items in io[] table + 3 fds
	close(fd); // Done exporting


	// ----------------------------------------------------------------
	// Set up uinput

	// Traditionally we've used /dev/uinput for generating key events,
	// but see notes below....
	if((fd = open("/dev/uinput", O_WRONLY | O_NONBLOCK)) < 0)
		err("Can't open /dev/uinput");
	if(ioctl(fd, UI_SET_EVBIT, EV_KEY) < 0)
		err("Can't SET_EVBIT");
	for(i=0; io[i].pin >= 0; i++) {
		if(io[i].key != GND) {
			if(ioctl(fd, UI_SET_KEYBIT, io[i].key) < 0)
				err("Can't SET_KEYBIT");
		}
	}
	if(ioctl(fd, UI_SET_KEYBIT, vulcanKey) < 0) err("Can't SET_KEYBIT");
	struct uinput_user_dev uidev;
	memset(&uidev, 0, sizeof(uidev));
	snprintf(uidev.name, UINPUT_MAX_NAME_SIZE, "retrogame");
	uidev.id.bustype = BUS_USB;
	uidev.id.vendor  = 0x1;
	uidev.id.product = 0x1;
	uidev.id.version = 1;
	if(write(fd, &uidev, sizeof(uidev)) < 0)
		err("write failed");
	if(ioctl(fd, UI_DEV_CREATE) < 0)
		err("DEV_CREATE failed");

	// SDL2 (used by some newer emulators) wants /dev/input/eventX
	// instead -- BUT -- this is the odd thing, and I don't fully
	// understand the why -- eventX only exists if a physical USB
	// keyboard has been connected, OR IF /dev/uinput in the code
	// above has been opened and set up.  Skip the prior steps and
	// it won't happen (this wasn't necessary in earlier versions,
	// could just go right to this step for SDL2, so not sure what's
	// up).  Since we might be running on an earlier system, we'll
	// start with uinput by default, then override the value of fd
	// only *if* eventX exists, should cover both cases.

	// The 'X' in eventX is a unique identifier (typically a numeric
	// digit or two) for each input device, dynamically assigned as
	// USB input devices are plugged in or disconnected (or when the
	// above code in retrogame runs).  As it's dynamically assigned,
	// we can't rely on a fixed number -- it will vary if there's a
	// keyboard connected when the program starts.


	struct dirent **namelist;
	int             n;
	char            evName[100] = "";

	if((n = scandir("/sys/devices/virtual/input",
	  &namelist, filter1, NULL)) > 0) {
		// Got a list of device(s).  In theory there should
		// be only one that makes it through the filter (name
		// matches retrogame)...if there's multiples, only
		// the first is used.  (namelist can then be freed)
		char path[100];
		sprintf(path, "/sys/devices/virtual/input/%s",
		  namelist[0]->d_name);
		for(i=0; i<n; i++) free(namelist[i]);
		free(namelist);
		// Within the given device path should be subpath with
		// the name 'eventX' (X varies), again theoretically
		// should be only one, first in list is used.
		if((n = scandir(path, &namelist, filter2, NULL)) > 0) {
			sprintf(evName, "/dev/input/%s",
			  namelist[0]->d_name);
			for(i=0; i<n; i++) free(namelist[i]);
			free(namelist);
		}
	}

	if(!evName[0]) { // Nothing found?  Use fallback method...
		// Kinda lazy skim for last item in /dev/input/event*
		// This is NOT guaranteed to be retrogame, but if the
		// above method fails for some reason, this may be
		// adequate.  If there's a USB keyboard attached at
		// boot, it usually instantiates in /dev/input before
		// retrogame, so even if it's then removed, the index
		// assigned to retrogame stays put...thus the last
		// index mmmmight be what we need.
		char        name[32];
		struct stat st;
		for(i=99; i>=0; i--) {
			sprintf(name, "/dev/input/event%d", i);
			if(!stat(name, &st)) break; // last valid device
		}
		strcpy(evName, (i >= 0) ? name : "/dev/input/event0");
	}


	if((fd2 = open(evName, O_WRONLY | O_NONBLOCK)) >= 0)
		fd = fd2; // Override fd; write to eventX instead

	// Initialize input event structures
	memset(&keyEv, 0, sizeof(keyEv));
	keyEv.type  = EV_KEY;
	memset(&synEv, 0, sizeof(synEv));
	synEv.type  = EV_SYN;
	synEv.code  = SYN_REPORT;
	synEv.value = 0;

	// 'fd' is now open file descriptor for issuing uinput events


	// ----------------------------------------------------------------
	// Monitor GPIO file descriptors for button events.  The poll()
	// function watches for GPIO IRQs in this case; it is NOT
	// continually polling the pins!  Processor load is near zero.
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

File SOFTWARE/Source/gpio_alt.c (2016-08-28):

/*
    Utility to switch Raspberry-Pi GPIO pin functions
    Tim Giles 01/04/2013
 
    Usage:
    $ gpio_alt -p PIN_NUMBER -f ALT_NUMBER
 
    Based on RPi code from Dom and Gert, 15-Feb-2013, <http://elinux.org/RPi_Low-level_peripherals#C_2>
    and Gnu getopt() example <http://www.gnu.org/software/libc/manual/html_node/Example-of-Getopt.html#Example-of-Getopt>
    */
 
    #include <ctype.h>
    #include <stdio.h>
    #include <stdlib.h>
    #include <unistd.h>
    #include <fcntl.h>
    #include <sys/mman.h>
 
    #define BCM2708_PERI_BASE        0x20000000
    #define GPIO_BASE                (BCM2708_PERI_BASE + 0x200000) /* GPIO controller */
    #define PAGE_SIZE (4*1024)
    #define BLOCK_SIZE (4*1024)
 
    int  mem_fd;
    void *gpio_map;
    volatile unsigned *gpio;
    void setup_io();
 
    // GPIO setup macros. Always use INP_GPIO(x) before using OUT_GPIO(x) or SET_GPIO_ALT(x,y)
    #define INP_GPIO(g) *(gpio+((g)/10)) &= ~(7<<(((g)%10)*3))
    #define OUT_GPIO(g) *(gpio+((g)/10)) |=  (1<<(((g)%10)*3))
    #define SET_GPIO_ALT(g,a) *(gpio+(((g)/10))) |= (((a)<=3?(a)+4:(a)==4?3:2)<<(((g)%10)*3))
 
    #define GPIO_SET *(gpio+7)  // sets   bits which are 1 ignores bits which are 0
    #define GPIO_CLR *(gpio+10) // clears bits which are 1 ignores bits which are 0
 
 
 
    int main (int argc, char **argv) {
      int opt, flag, n_pin, n_alt;
      flag=0;
 
      while ((opt = getopt (argc, argv, "hp:f:")) != -1) {
        switch (opt) {
        case 'h':
          break;
        case 'p':
          n_pin = atoi(optarg); flag |= 0b0001; break;
        case 'f':
          n_alt = atoi(optarg); flag |= 0b0010; break;
        case '?':
          // getopt() prints error messages, so don't need to repeat them here
          return 1;
        default:
          abort ();
        }
      }
     
      if (flag != 0b0011) {
        fprintf (stderr, "Usage:\n$ gpio_alt -p PIN_NUM -f FUNC_NUM\n");
        return 1;
      }
     
      setup_io(); // Set up gpi pointer for direct register access
      INP_GPIO(n_pin);  // Always use INP_GPIO(x) before using SET_GPIO_ALT(x,y)
      SET_GPIO_ALT(n_pin, n_alt);
     
      printf("Set pin %i to alternative-function %i\n", n_pin, n_alt);
     
      return 0;
    }
 
 
 
    void setup_io() {
       /* open /dev/mem */
       if ((mem_fd = open("/dev/mem", O_RDWR|O_SYNC) ) < 0) {
          printf("can't open /dev/mem \n");
          exit(-1);
       }
 
       /* mmap GPIO */
       gpio_map = mmap(
          NULL,             //Any adddress in our space will do
          BLOCK_SIZE,       //Map length
          PROT_READ|PROT_WRITE,// Enable reading & writting to mapped memory
          MAP_SHARED,       //Shared with other processes
          mem_fd,           //File to map
          GPIO_BASE         //Offset to GPIO peripheral
       );
 
       close(mem_fd); //No need to keep mem_fd open after mmap
 
       if (gpio_map == MAP_FAILED) {
          printf("mmap error %d\n", (int)gpio_map);//errno also set!
          exit(-1);
       }
 
       // Always use volatile pointer!
       gpio = (volatile unsigned *)gpio_map;
    }

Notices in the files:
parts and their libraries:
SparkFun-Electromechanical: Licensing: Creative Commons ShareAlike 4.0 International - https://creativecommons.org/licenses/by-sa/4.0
